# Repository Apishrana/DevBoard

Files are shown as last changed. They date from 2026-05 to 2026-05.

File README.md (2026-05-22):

# ATmega328 USB-C Devboard

Custom ATmega328-P based devboard for Arduino-like systems.

## Images

### Front

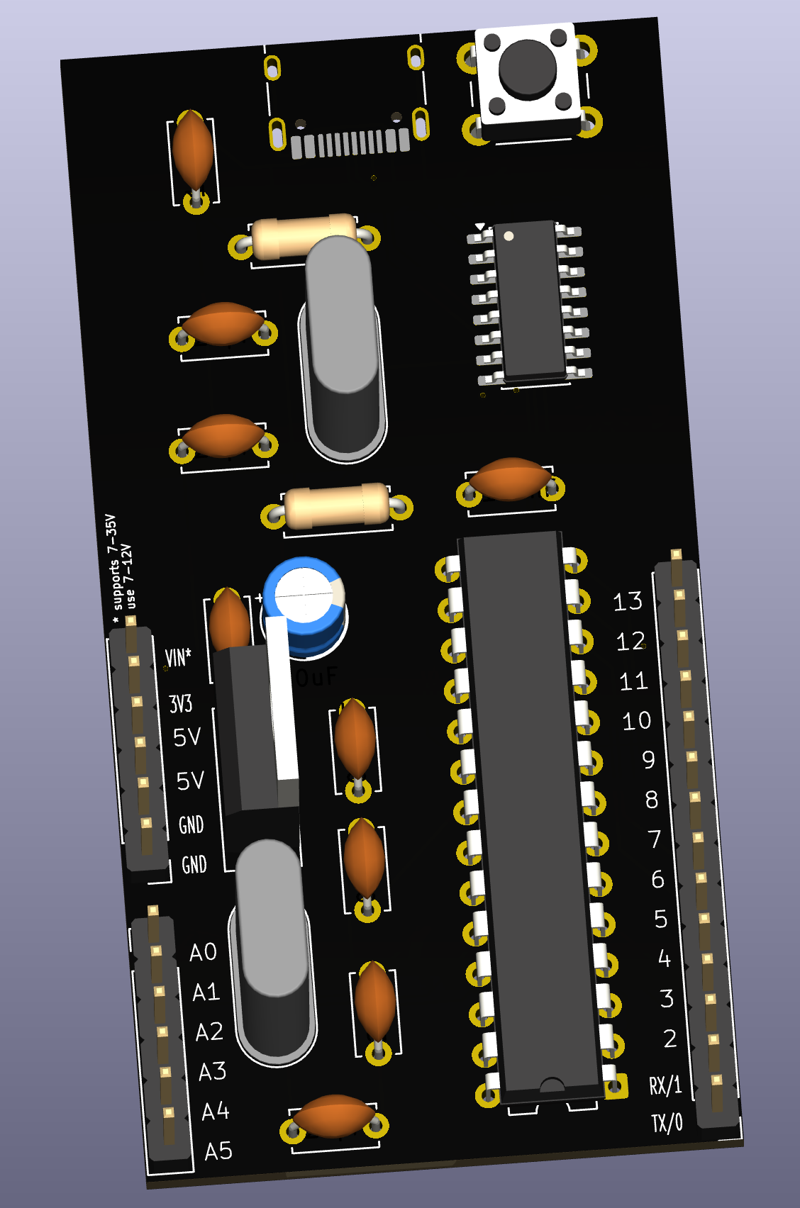
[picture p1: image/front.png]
Front


### Back

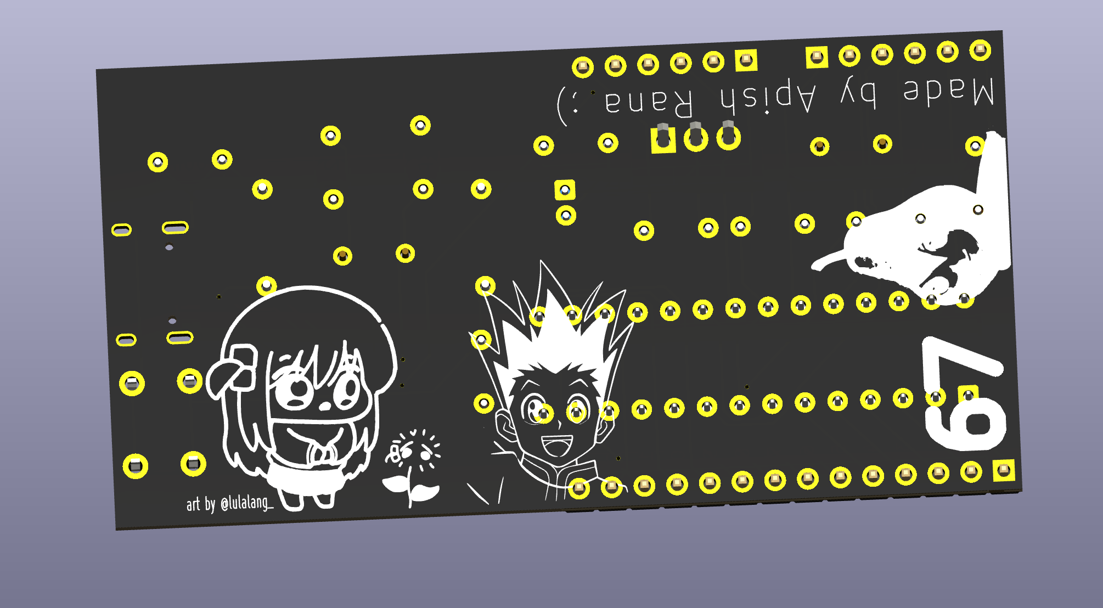
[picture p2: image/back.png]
Back


### PCB

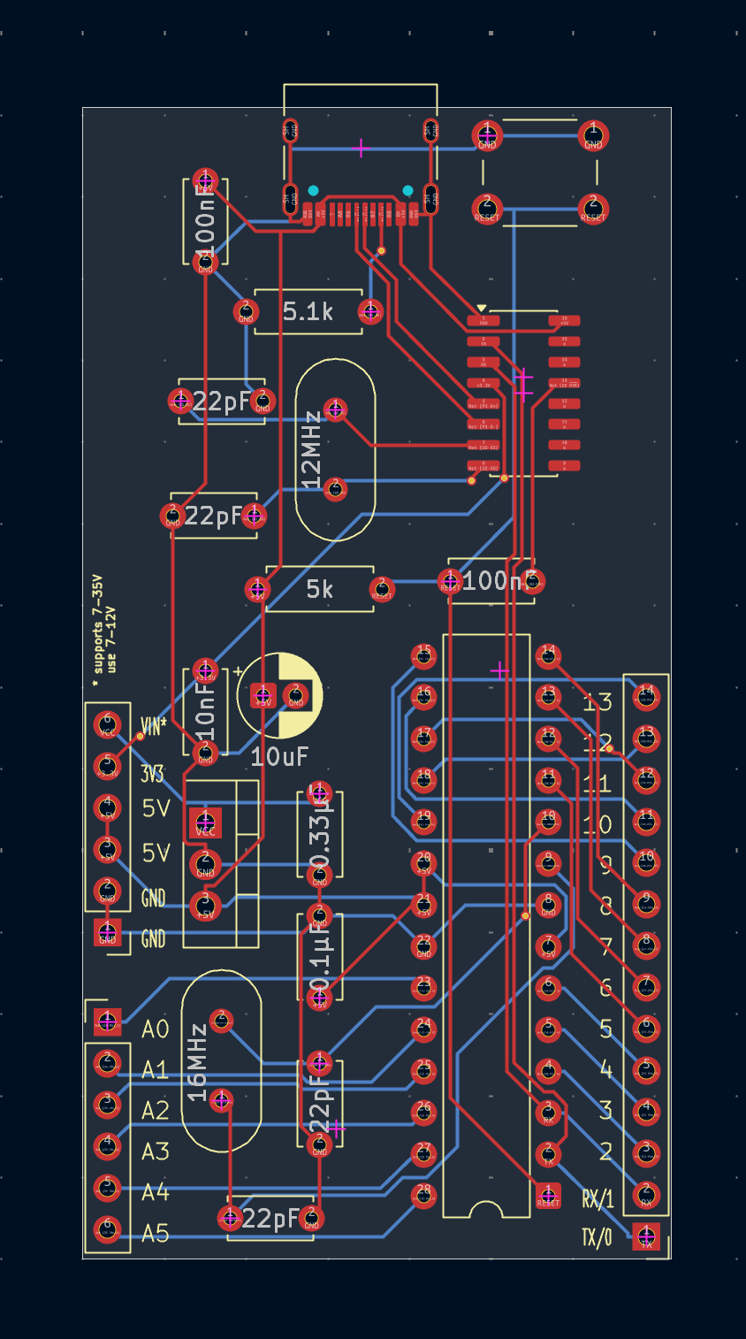
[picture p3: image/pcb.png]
PCB


### Schematic

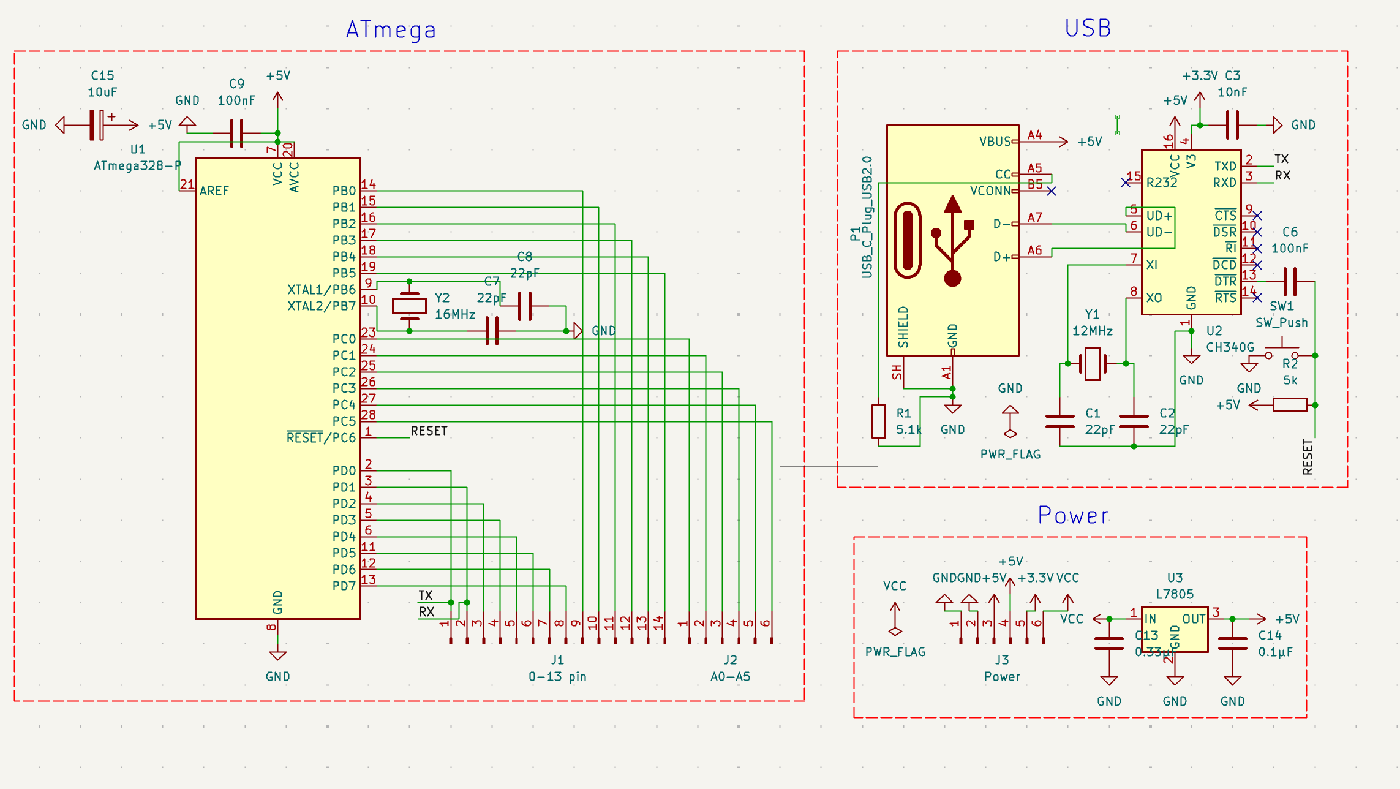
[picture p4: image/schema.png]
Schematic


---

## Features

- ATmega328-P as Microcontroller
- USB-C Support
- CH340G for USB-to-Serial
- Digital Pin `0-13`
- Analog Pin `A0-A5`
- 5 V VIN Regulation with L7805
- Reset Button

---

## Repository Structure

```text
.
├── BOM.csv
├── Devboard.kicad_pcb
├── Devboard.kicad_prl
├── Devboard.kicad_pro
├── Devboard.kicad_sch
├── grbr
│   ├── Devboard-B_Cu.gbl
│   ├── Devboard-B_Mask.gbs
│   ├── Devboard-B_Paste.gbp
│   ├── Devboard-B_Silkscreen.gbo
│   ├── Devboard-Edge_Cuts.gm1
│   ├── Devboard-F_Cu.gtl
│   ├── Devboard-F_Mask.gts
│   ├── Devboard-F_Paste.gtp
│   ├── Devboard-F_Silkscreen.gto
│   ├── Devboard-job.gbrjob
│   ├── Devboard-NPTH.drl
│   ├── Devboard-PTH.drl
│   └── Devboard.zip
├── image
│   ├── back.png
│   ├── front.png
│   ├── pcb.png
│   └── schema.png
└── README.md

3 directories, 23 files
```

---

## Board Details

- Microcontroller: `ATmega328-P`
- USB Serial: `CH340G`
- Main Clock: `16 MHz`
- USB Serial Clock: `12 MHz`
- Input Power: USB-C or `VIN`

`VIN`: `7-12 V`

---

## Author

Created by [Apish Rana](https://github.com/Apishrana)

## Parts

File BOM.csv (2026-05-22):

Name | Purpose | Quantity | Link
4.7k Ohm Resistor | 1 | https://robocraze.com/products/4-7k-resistor-pack-of-10?variant=40194232647833
4-Pins DIP Momentary Square Tactile Push Button Switch 10 Pieces - 6x6x8mm | 1 | https://robocraze.com/products/4-pins-dip-momentary-square-tactile-push-button-switch-10-pieces-6x6x8mm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
ATmega328P-U PDIP-28 8 BIT Microcontroller IC | 1 | https://robocraze.com/products/atmega328?variant=40192377454745
Aluminum Heatsink Cooling for LM7805 IC Transistor(25mm) | 1 | https://robocraze.com/products/aluminum-heatsink-cooling-for-lm7805-ic-transistor25mm?variant=43224374804704
LM7805 IC - 5V Positive Voltage Regulator IC | 1 | https://robocraze.com/products/7805-ic?variant=40192321093785
40x1 Pin 2.54mm Pitch Male Berg Strip | 1 | https://robocraze.com/products/40x1-pin-2-54mm-pitch-male-berg-strip?variant=43046522650848
1x40 2.54mm Pitch Female Berg Strip Header (Right Angle) | 1 | https://robocraze.com/products/1x40-2-54mm-pitch-female-berg-strip-header-right-angle?variant=43194093273312
12 MHz Crystal Oscillator | 1 | https://robocraze.com/products/12-mhz-crystal-oscillator-pack-of-10?variant=40194255978649
28 Pin Narrow DIP IC Socket Base Adaptor | 2 | https://robu.in/product/28-pin-narrow-dip-ic-socket-base-adaptor-pack-of-5/
HC49/U 16MHz Crystal Oscillator | 2 | https://robu.in/product/hc49-s-16mhz-crystal-oscillator-pack-of-5/
ERS1HM100D11OT-AISHI -10uF 50V ±20% Plugin,D5xL11mm Aluminum Electrolytic Capacitors - Leaded ROHS | 6 | https://robu.in/product/ers1hm100d11ot-aishi-10uf-50v-%c2%b120-plugind5xl11mm-aluminum-electrolytic-capacitors-leaded-rohs/
TYPE-C-31-M-12-Hroparts-5A 1 16P Female Type-C SMD USB Connectors ROHS | 2 | https://robu.in/product/type-c-31-m-12-hroparts-5a-1-16p-female-type-c-smd-usb-connectors-rohs/
22pF 50V Ceramic Capacitor - DIP | 23 | https://robu.in/product/22pf-50v-ceramic-capacitor-dip-pack-of-50/
10nF (0.01uF - 2E103J) - 250V Polyester Film Capacitor | 5 | https://robu.in/product/10nf-0-01uf-2e103j-250v-polyester-film-capacitor-pack-of-10/
CH340G SOIC16 USB to Serial TTL-RS232 converter IC | 3 | https://robu.in/product/ch340g-soic16-usb-to-serial-ttl-rs232-converter-ic/

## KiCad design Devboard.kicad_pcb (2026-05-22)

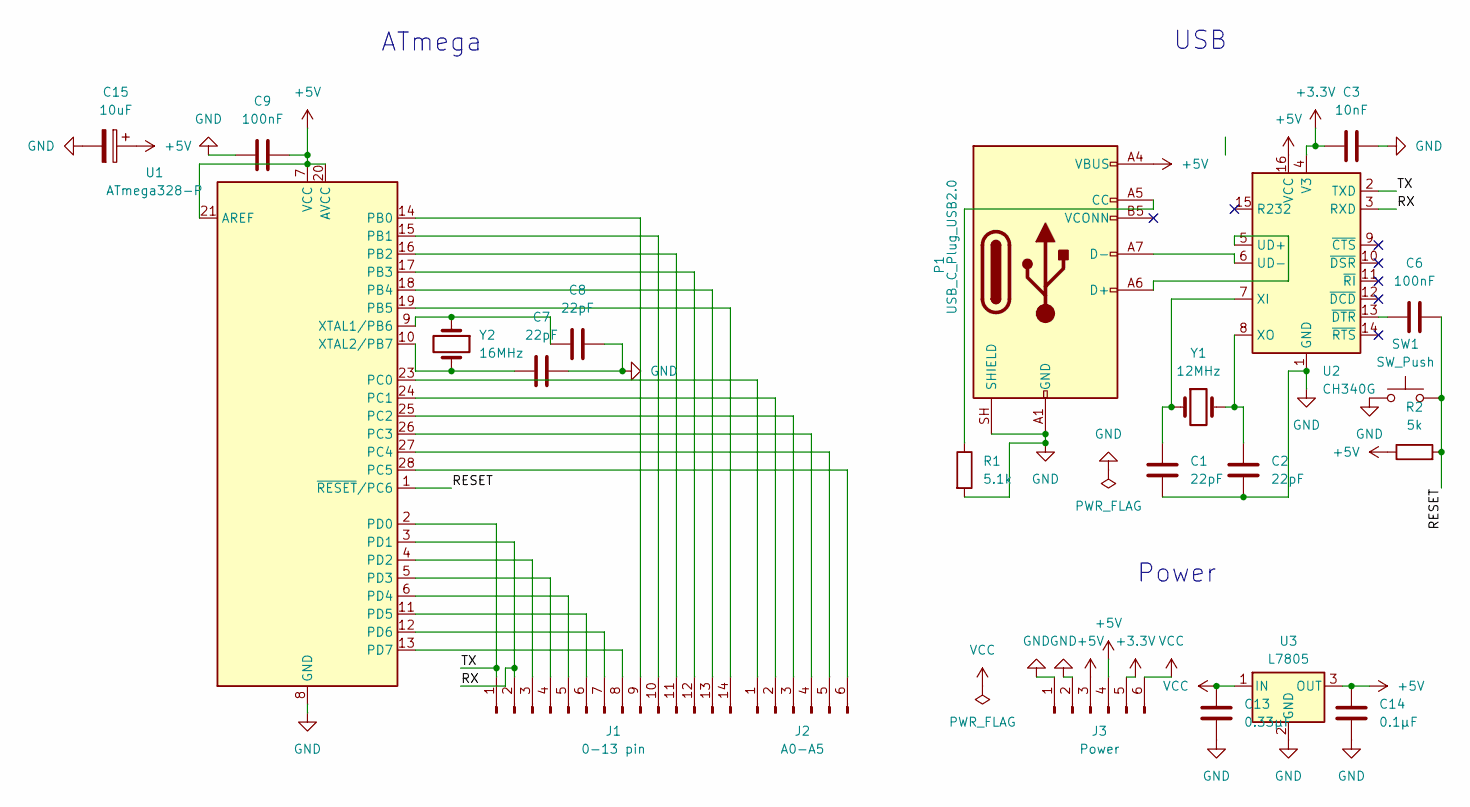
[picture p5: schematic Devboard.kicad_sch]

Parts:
C1, C2, C7, C8: 22pF; C_Disc_D5.0mm_W2.5mm_P5.00mm
C3: 10nF; C_Disc_D5.0mm_W2.5mm_P5.00mm
C6, C9: 100nF; C_Disc_D5.0mm_W2.5mm_P5.00mm
C13: 0.33µF; C_Disc_D5.0mm_W2.5mm_P5.00mm
C14: 0.1µF; C_Disc_D5.0mm_W2.5mm_P5.00mm
C15: 10uF; CP_Radial_D5.0mm_P2.00mm
J1: 0-13 pin; PinHeader_1x14_P2.54mm_Vertical
J2: A0-A5; PinHeader_1x06_P2.54mm_Vertical
J3: Power; PinHeader_1x06_P2.54mm_Vertical
P1: USB_C_Plug_USB2.0; USB_C_Receptacle_HRO_TYPE-C-31-M-12
R1: 5.1k; R_Axial_DIN0207_L6.3mm_D2.5mm_P7.62mm_Horizontal
R2: 5k; R_Axial_DIN0207_L6.3mm_D2.5mm_P7.62mm_Horizontal
SW1: SW_Push; SW_PUSH_6mm_H5mm
U1: ATmega328-P; DIP-28_W7.62mm
U2: CH340G; SOIC-16_3.9x9.9mm_P1.27mm
U3: L7805; TO-220-3_Vertical
Y1: 12MHz; Crystal_HC49-U_Vertical
Y2: 16MHz; Crystal_HC49-U_Vertical

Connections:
+3.3V: C3.1, J3.5, U2.4 (V3)
+5V: C9.1, C14.1, C15.1, J3.3, J3.4, P1.A4 (VBUS), P1.A9 (VBUS), P1.B4 (VBUS), P1.B9 (VBUS), R2.1, U1.7 (VCC), U1.20 (AVCC), U1.21 (AREF), U2.16 (VCC), U3.3 (OUT)
/RESET: C6.1, R2.2, SW1.2, U1.1 (~RESET/PC6)
/RX: J1.2, U1.3 (PD1), U2.3 (RXD)
/TX: J1.1, U1.2 (PD0), U2.2 (TXD)
GND: C1.2, C2.2, C3.2, C7.2, C8.2, C9.2, C13.2, C14.2, C15.2, J3.1, J3.2, P1.A1 (GND), P1.A12 (GND), P1.B1 (GND), P1.B12 (GND), P1.SH (SHIELD), R1.2, SW1.1, U1.8 (GND), U1.22 (GND), U2.1 (GND), U3.2 (GND)
unnamed: J1.3, U1.4 (PD2)
unnamed: J1.4, U1.5 (PD3)
unnamed: J1.5, U1.6 (PD4)
unnamed: J1.6, U1.11 (PD5)
unnamed: J1.7, U1.12 (PD6)
unnamed: J1.8, U1.13 (PD7)
unnamed: J1.9, U1.14 (PB0)
unnamed: J1.10, U1.15 (PB1)
unnamed: J1.11, U1.16 (PB2)
unnamed: J1.12, U1.17 (PB3)
unnamed: J1.13, U1.18 (PB4)
unnamed: J1.14, U1.19 (PB5)
unnamed: J2.1, U1.23 (PC0)
unnamed: J2.2, U1.24 (PC1)
unnamed: J2.3, U1.25 (PC2)
unnamed: J2.4, U1.26 (PC3)
unnamed: J2.5, U1.27 (PC4)
unnamed: J2.6, U1.28 (PC5)
unnamed: P1.A5 (CC), R1.1
unnamed: P1.A6 (D+), U2.5 (UD+)
unnamed: P1.A7 (D-), U2.6 (UD-)
unnamed: C8.1, U1.9 (XTAL1/PB6), Y2.1
unnamed: C7.1, U1.10 (XTAL2/PB7), Y2.2
unnamed: C1.1, U2.7 (XI), Y1.1
unnamed: C2.1, U2.8 (XO), Y1.2
unnamed: C6.2, U2.13 (~DTR)
VCC: C13.1, J3.6, U3.1 (IN)

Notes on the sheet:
USB
Power
ATmega

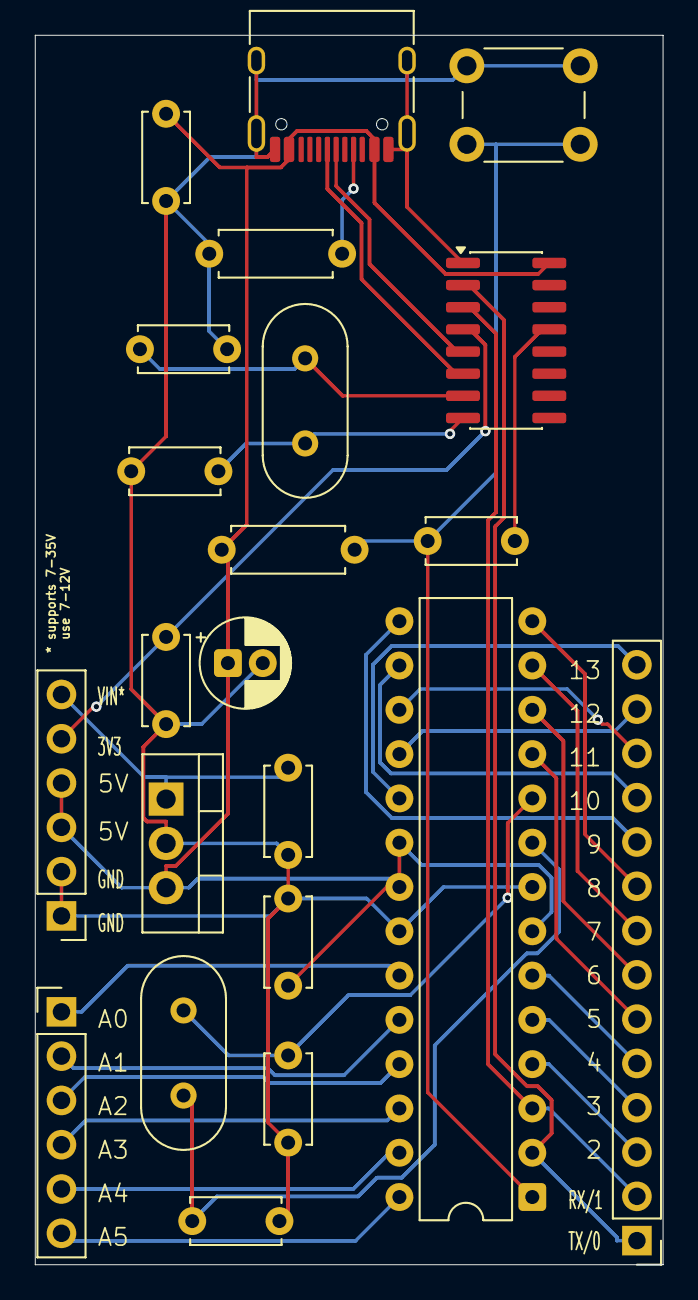
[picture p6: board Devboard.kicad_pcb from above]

Board: 2 copper layers, 36.0 x 70.5 mm, 22 parts (0 on the bottom side), 33 nets.

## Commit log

2026-05-19 Added pcb lbeling
    [Devboard.kicad_pcb]
2026-05-22 final dessine
    [Devboard-B_Cu.gbl, Devboard-B_Mask.gbs, Devboard-B_Paste.gbp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]
